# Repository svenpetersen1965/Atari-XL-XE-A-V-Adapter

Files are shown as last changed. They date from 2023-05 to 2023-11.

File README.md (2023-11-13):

# Atari-XL-XE-A-V-Adapter
This is an A/V-Adapter for the Atari 8bit XL and XE. It provides a connector for S-Video, which will work with the XE models and with XL models, that have the S-Video mod.

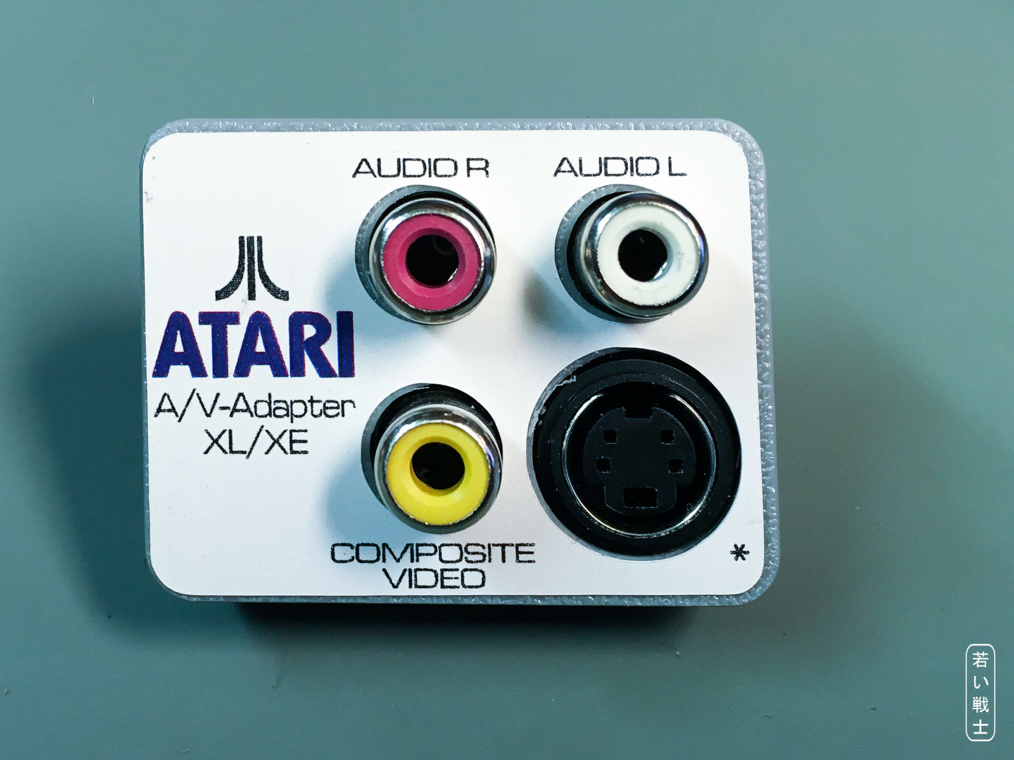
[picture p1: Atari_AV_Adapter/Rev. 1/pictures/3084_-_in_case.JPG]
Atari XL/XE A/V Adapter


The BOM value (13.11.2023) for the PCB and components is 10.87€. This does not include the 3D printed case or any shipping fees to be paid for the components.

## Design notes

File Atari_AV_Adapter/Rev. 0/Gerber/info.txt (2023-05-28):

      
       Board: Atari_AV-Adapter
       Rev.:  0
  
       Files:
       ======
  
       All Gerber files are generated in extended gerber format (RS274X)
       *.TOP        : Film top copper
       *.BOT        :  -"- bottom copper
       *.STC        :  -"- top soldermask 
       *.STS        :  -"- bottom soldermask
       *.PLC        :  -"- silk screen top
       *.PLS        :  -"- silk screen bottom
       *.DK         : Drills plated Through (Excellon)
       *.NDK        : Drills not plated Through (Excellon)
       *.OUT        : Board outline

       Board Size:
       ===========
       Length     :   39.0 mm
       Width      :   29.0 mm
       Thickness  :   1.6 mm
       Material   :   FR 4
       Copper     :   35 um
       Surface    :   HASL
       
       Remarks:
       ========
       Width >= 8mil
       Distance >= 6mil
       Drill >= 0.6mm

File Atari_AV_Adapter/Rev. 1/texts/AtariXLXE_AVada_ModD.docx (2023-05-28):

Atari XL/XE A/V-Adapter Rev. 1

Module Description

# Introduction

The Atari XL/XE-Adapter serves as a breakout module for the 5-pin A/V jack, which allows using off the shelve cables of desired length and quality for connecting the Atari XL/XE to video/audio equipment.

The adapter is passive, it does not improve the video quality, but it helps to prevent video degradation. The S-Video jack works with Atari XL (that are modified only) and XE. The adapter does not generate S-Video!

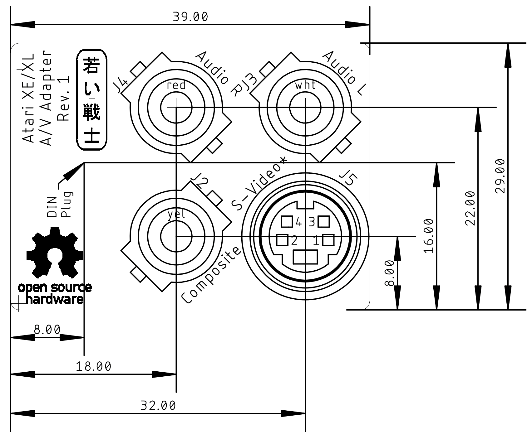
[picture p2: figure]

Figure 1: Dimensions of the PCB

The two audio jacks (Audio L and Audio R) are connected to the same signal, the (mono) Audio Out of the Atari.

A 3D printable case can be found in the project folder as well as a label for this case. The case for Rev. 0 is different from the case for Rev. 1.

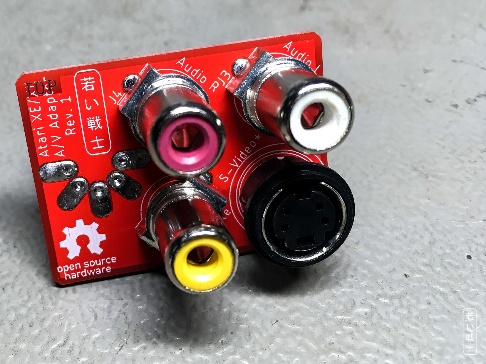
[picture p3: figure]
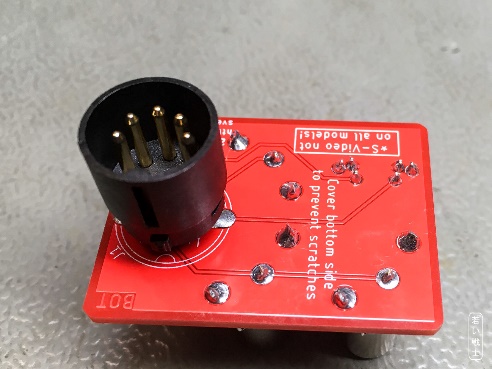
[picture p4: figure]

Figure 2: Top and bottom side of the assembled Atari A/V-Adapter

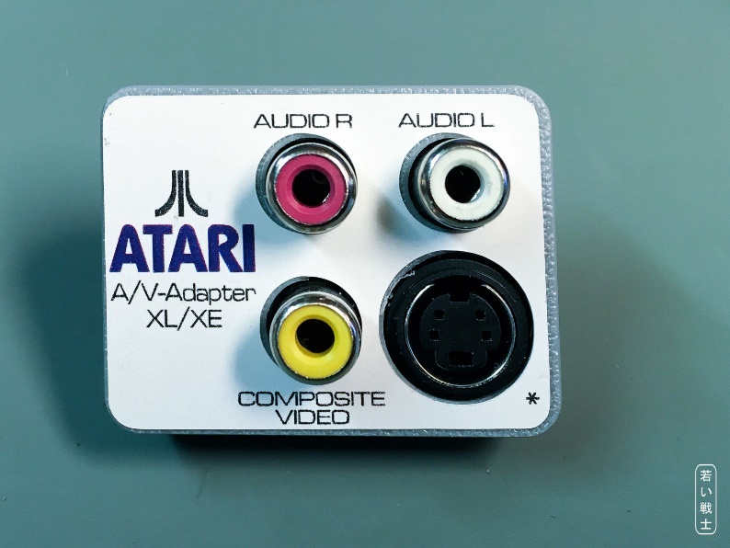
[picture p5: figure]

Figure 3: Atari A/V-Adapter installed in the 3D-printed case

# Connectors

## A/V-Plug – J1

The A/V-Plug for the Atari XE (XL) is the inner part of a Lumberg SV 50 DIN-Plug (180°).

Pin | Signal
1 | Luminance*
2 | GND
3 | Audio Out (mono)
4 | Composite Video
5 | CHROMA*

*XL (with S-Video mod only) and XE

## RCA-Jacks – J2, J3, J4

Connector | Signal
J2 | Composite Video
J3 | Audio Out L (mono!)
J4 | Audio Out R (mono!)

## Mini-DIN (S-Video) jack – J5

A vertical PCB mount Mini-DIN jack (4 circuits)

Pin | Signal
1 | GND (Luminance)
2 | GND (Chrominance)
3 | Luminance
4 | Chrominance

# The DIN-Plug

The DIN-Plug is an essential part of this development. It is the inner part of a Lumberg SV 50 connector, which is not cheap, but it is definitely worth the money, since the flange is taking the forces introduced by the weight of the adapter and the cables. This way, the set-up is not hanging from the contacts, which might even damage those. Do not use a cheap connector without a flange, here.

# Assembly

First, the DIN connector has to be soldered. The pins should be aligned flush to the top side of the PCB. This can be accomplished by putting the PCB top down on a heat resistant, flat surface. Then solder one pin from the top (the solder pads are shaped in a way, that allows doing so), check, if it is really flush and the connector is perpendicular to the board, then solder the remaining pins.

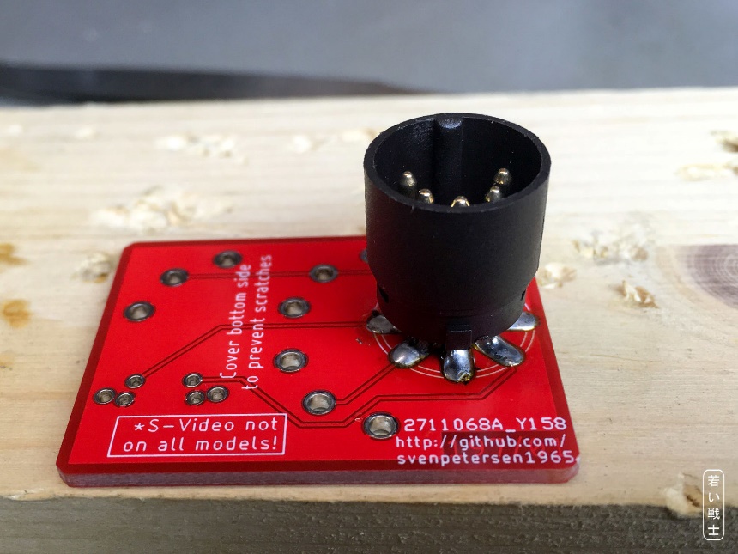
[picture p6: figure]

Figure 4: Aligning the DIN-Connector

Now, place and solder the mini-DIN and finally the RCA jacks. They should be well aligned, too. The ground pins might require more energy to be soldered, so the use of a thick solder tip is recommended and may be even a higher temperature (450°C). After soldering, the pins should be trimmed (shorter than 1.5mm), so they fit into the 3D-Printed case. If you do not use a case, cover the pins with something like duct tape or small drops of hot glue to prevent scratching the case of your Atari.

# Compatibility

The A/V Adapter is compatible with the Atari 8-bit computers XL (composite only) and XE and modified XL for S-Video.

# Acknowledgement

I thank my cooperation partner for this project, Michal Polák. He initiated the project, provided me with the information and tested the A/V Adapter with other computers than the 800XL.

# Revision History

## Rev. 0

- Fully functional prototype

## Rev. 0 → Rev. 1

- The device is turned right, the notch of the DIN and mini-DIN connectors points up (again)
- New case (Rev. 1) required

AtariXLXE_AVada_ModD.docx 28.05.2023 08:06 Drafted by Sven Petersen Page 2 of 2 Doc.-No.: 197-6-01-02

AtariXLXE_AVada_ModD.docx 28.05.2023 08:06 Drafted by Sven Petersen Page 1 of 1 Doc.-No.: 000-6-00-00

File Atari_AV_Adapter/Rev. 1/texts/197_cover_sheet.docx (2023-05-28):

Project Documentation

Atari XL/XE A/V-Adapter

Project number: 197

Revision: 1

Date: 15.11.2022


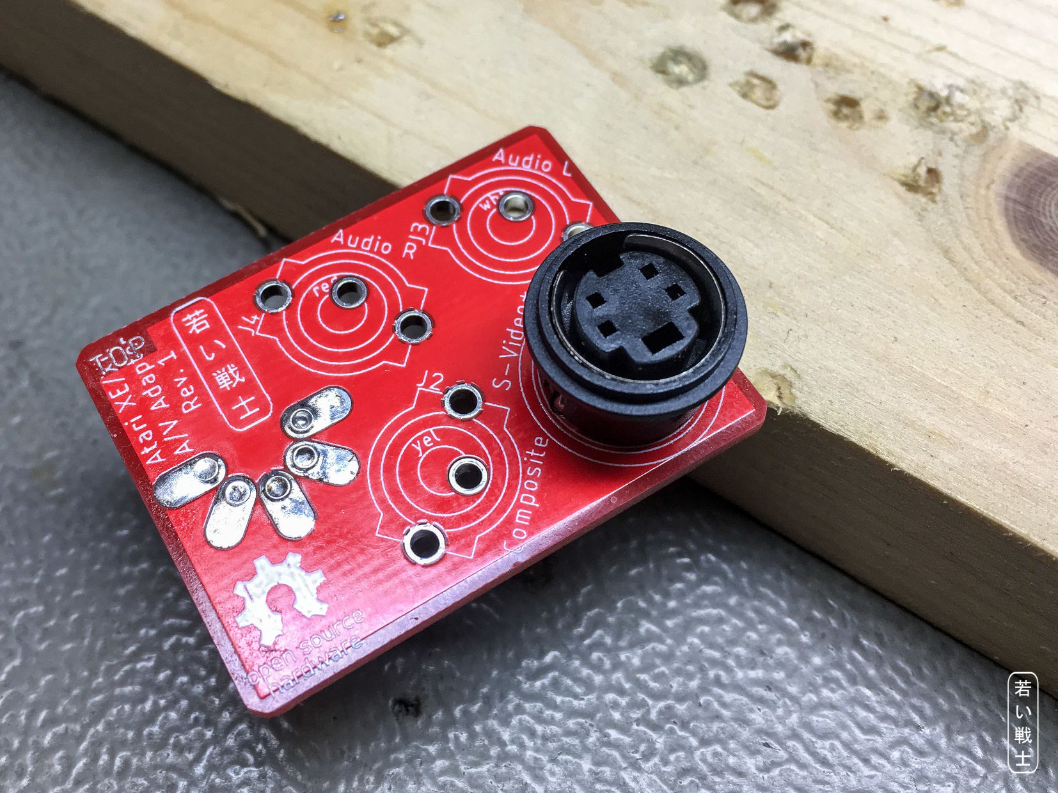
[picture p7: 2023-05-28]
Atari_AV_Adapter/Rev. 1/pictures/2986_-_MiniDIN.JPG

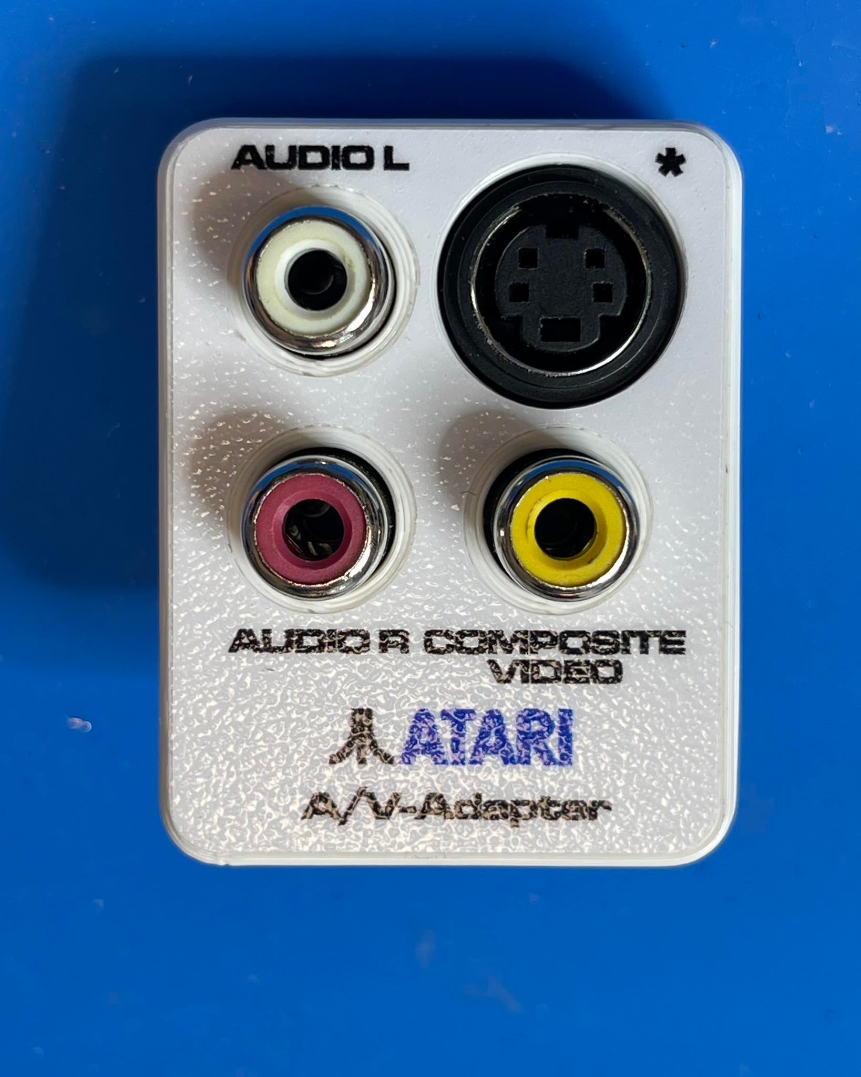
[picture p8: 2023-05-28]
Atari_AV_Adapter/Rev. 0/pictures/310895890_1458096414676044_7788498027069348975_n.jpg

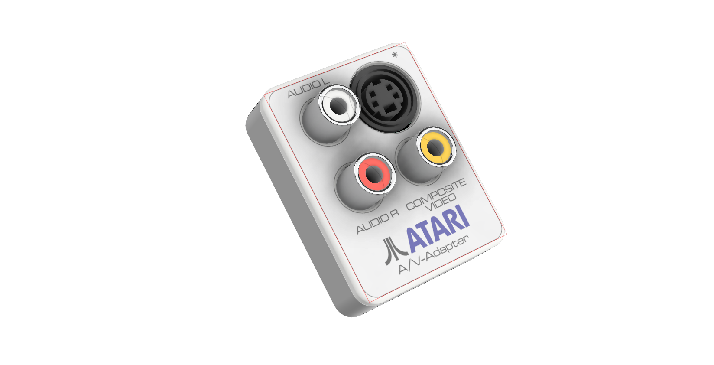
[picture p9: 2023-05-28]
Atari_AV_Adapter/Rev. 0/pictures/Atari A_V Adapter case v0 v2.png

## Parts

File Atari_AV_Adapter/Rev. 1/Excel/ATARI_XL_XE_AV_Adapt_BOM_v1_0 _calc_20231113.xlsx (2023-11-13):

Atari XL/XE A/V-Adaptor Rev. 1
Bill of Material Rev. 1.0 Calculation of 13.11.2023
Pos. | Qty | Value | €/ea | € | Comment
1 | 1 | 197-2-01-01 | 1.00 € | 1.00 € | 2 layer, Cu 35µ, HASL, 39.0mm x 29.0mm, 1.6mm FR4
2 | 1 | RCJ-022 | 1.26 € | 1.26 € | CUI Inc., RCA jack, vertical, red. Mouser: 490-RCJ-022, Digikey: CP-1407-ND. Alternative part: Keystone 577
3 | 1 | RCJ-023 | 1.26 € | 1.26 € | CUI Inc., RCA jack, vertical, white. Mouser: 490-RCJ-023, Digikey: CP-1408-ND. Alternative part: Keystone 584
4 | 1 | RCJ-024 | 1.26 € | 1.26 € | CUI Inc., RCA jack, vertical, yellow. Mouser: 490-RCJ-024, Digikey: CP-1409-ND. Alternative part: Keystone 586
5 | 1 | SV50 | 5.25 € | 5.25 € | Inner part of Lumberg SV 50 (SV 50-8), e.G. Reichelt: LUM SV 50, Newark: 82AH3339 , Farnell: 3549652, TME.eu: SV50, alliedelec.com: 70151556
6 | 1 | solder bridge | 0 | 0.00 € | structure on PCB, close for proper operation
7 | 1 | RTC9028 | 0.84 € | 0.84 € | Mini-DIN, 4p, vertical. Not required for 5-pin and VIC-20. E.g. AliExpress:
 |  |  |  | 0.00 € | RTConnector: RTC9028 (https://www.aliexpress.com/item/4001075948319.html?channel=twinner)
 |  |  |  | 0.00 € | ebay.de (https://www.ebay.de/itm/5Stuck-Leiterplatten-Mount-4-Pin-Buchse-S-Jack-DVD-Mini-DIN-Sockel-Steckverbind/132869605733)
1 |  |  | Total | 10.87 €

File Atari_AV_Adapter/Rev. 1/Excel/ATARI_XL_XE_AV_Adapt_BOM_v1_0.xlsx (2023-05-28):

Atari XL/XE A/V-Adaptor Rev. 1
Bill of Material Rev. 1.0
Pos. | Qty | Value | Footprint | Ref.-No. | Comment
1 | 1 | 197-2-01-01 | 2 Layer | PCB Rev. 1 | 2 layer, Cu 35µ, HASL, 39.0mm x 29.0mm, 1.6mm FR4
2 | 1 | RCJ-022 | RCJ-02X | J4 | CUI Inc., RCA jack, vertical, red. Mouser: 490-RCJ-022, Digikey: CP-1407-ND. Alternative part: Keystone 577
3 | 1 | RCJ-023 | RCJ-02X | J3 | CUI Inc., RCA jack, vertical, white. Mouser: 490-RCJ-023, Digikey: CP-1408-ND. Alternative part: Keystone 584
4 | 1 | RCJ-024 | RCJ-02X | J2 | CUI Inc., RCA jack, vertical, yellow. Mouser: 490-RCJ-024, Digikey: CP-1409-ND. Alternative part: Keystone 586
5 | 1 | SV50 | SV50_INNER | J1 | Inner part of Lumberg SV 50 (SV 50-8), e.G. Reichelt: LUM SV 50, Newark: 82AH3339 , Farnell: 3549652, TME.eu: SV50, alliedelec.com: 70151556
6 | 1 | solder bridge |  | JP1 | structure on PCB, close for proper operation
7 | 1 | RTC9028 | MINIDIN4_V | J5 | Mini-DIN, 4p, vertical. Not required for 5-pin and VIC-20. E.g. AliExpress:
 |  |  |  |  | RTConnector: RTC9028 (https://www.aliexpress.com/item/4001075948319.html?channel=twinner)
 |  |  |  |  | ebay.de (https://www.ebay.de/itm/5Stuck-Leiterplatten-Mount-4-Pin-Buchse-S-Jack-DVD-Mini-DIN-Sockel-Steckverbind/132869605733)

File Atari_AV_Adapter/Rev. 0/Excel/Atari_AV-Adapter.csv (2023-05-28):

Qty | Value | Device | Package | Parts | Description
1 | OPEN_SOURCE_HW | OPEN_SOURCE_HW | OPENHW | U$25
1 | RCJ-022 | RCJ-02X | RCJ-02X | J4
1 | RCJ-023 | RCJ-02X | RCJ-02X | J3
1 | RCJ-024 | RCJ-02X | RCJ-02X | J2
1 | RTC9028 | RTC9028 | MINIDIN4_V | J5 | Mini-DIN, 4p, vertical
1 | SV50 | SV50 | SV50_INNER | J1

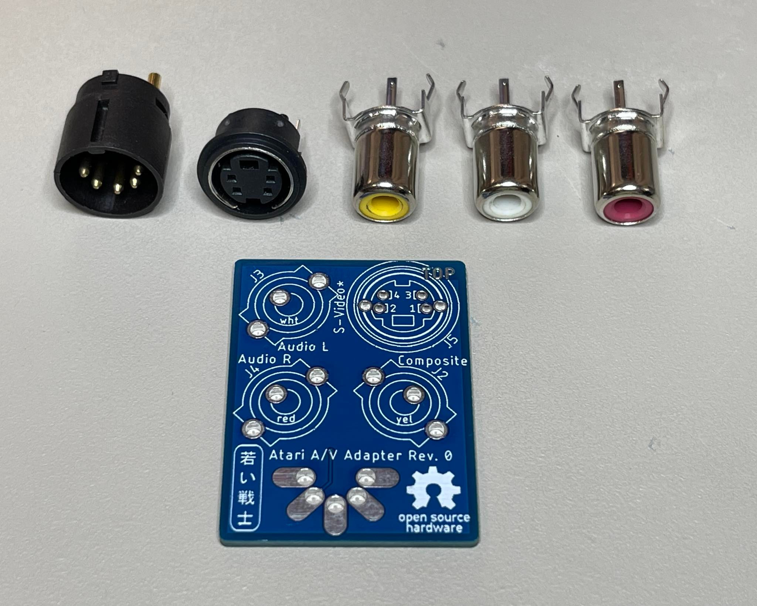
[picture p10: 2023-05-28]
Atari_AV_Adapter/Rev. 0/pictures/PCB_components.jpg

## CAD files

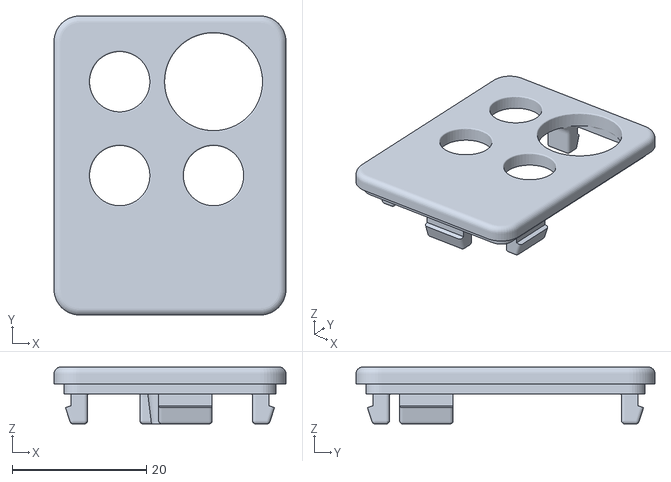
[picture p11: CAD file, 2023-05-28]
Atari_AV_Adapter/3D-printed case/Rev. 0/STL/Atari_AV_top_v0.stl
34.6 x 44.6 x 8.50

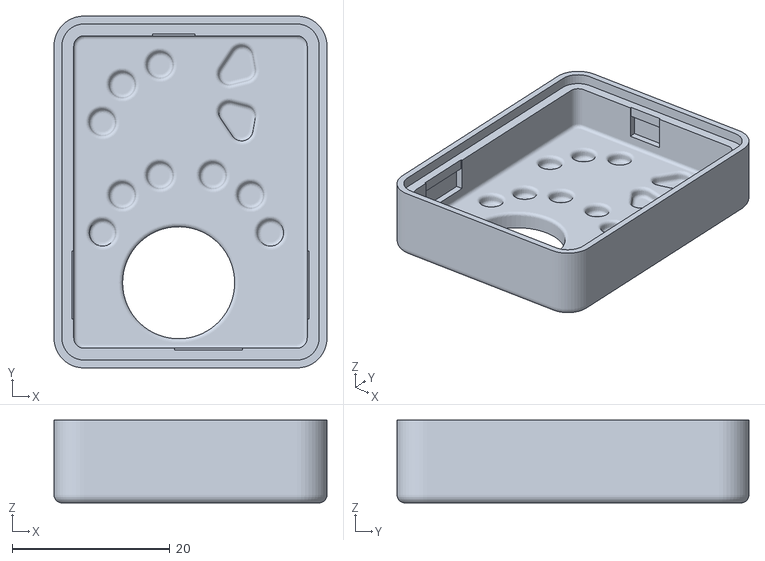
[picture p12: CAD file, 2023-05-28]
Atari_AV_Adapter/3D-printed case/Rev. 1/STL/Atari_AV_bottom_v1.stl
34.6 x 44.6 x 10.5

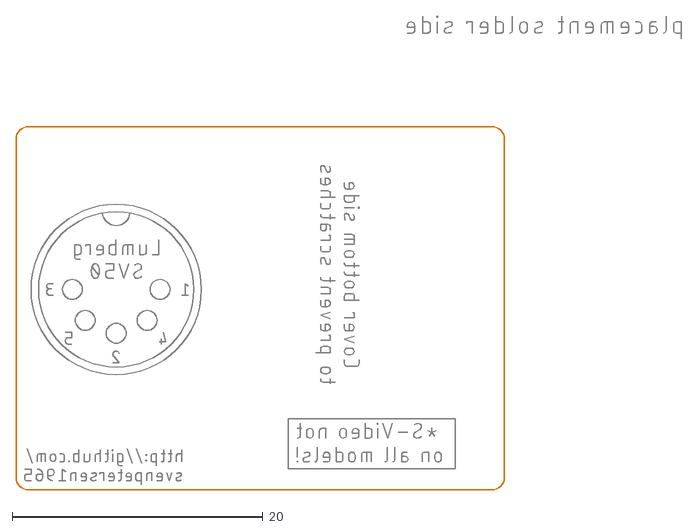
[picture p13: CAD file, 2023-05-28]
Atari_AV_Adapter/Rev. 1/dxf/Atari_AV-Adapter_bottom.dxf
53.1 x 37.8

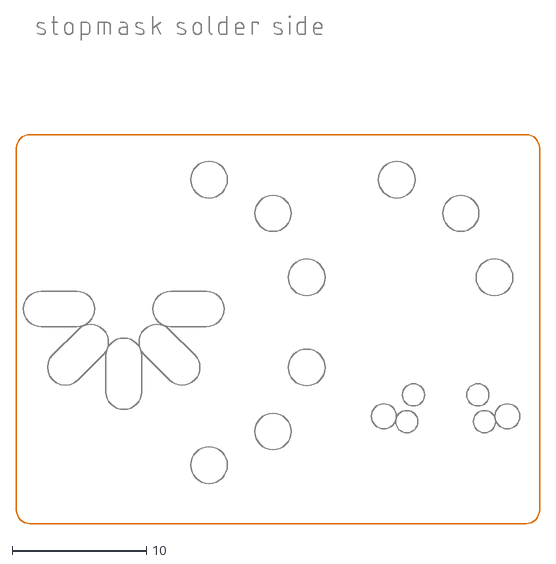
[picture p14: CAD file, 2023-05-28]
Atari_AV_Adapter/Rev. 1/dxf/Atari_AV-Adapter_bottom_pads.dxf
39.0 x 37.8

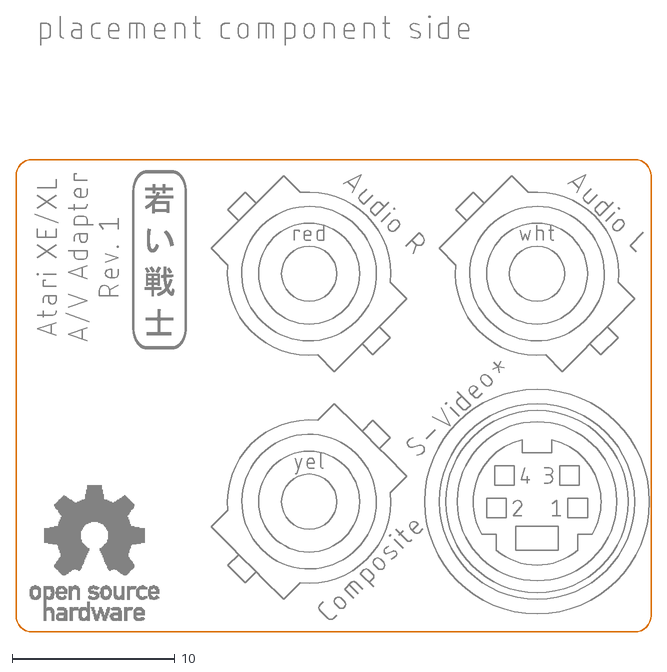
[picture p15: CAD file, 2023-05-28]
Atari_AV_Adapter/Rev. 1/dxf/Atari_AV-Adapter_top.dxf
39.0 x 37.8

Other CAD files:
Atari_AV_Adapter/3D-printed case/Rev. 0/STL/Atari_AV_bottom_v0.stl
Atari_AV_Adapter/3D-printed case/Rev. 0/Fusion 360/Atari AV Adapter case v0 v2.f3d
Atari_AV_Adapter/3D-printed case/Rev. 1/Fusion 360/Atari_XLXE_AV_Rev1.f3d

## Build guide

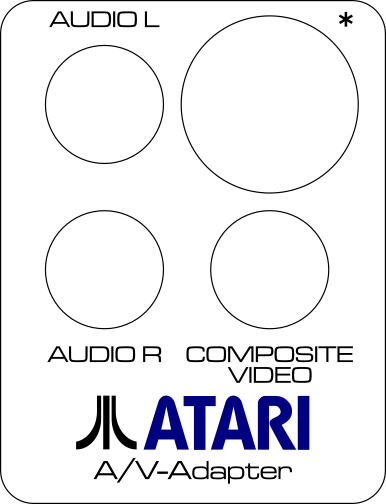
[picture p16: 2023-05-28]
Atari_AV_Adapter/3D-printed case/Rev. 0/Label/atari_AV_label.png

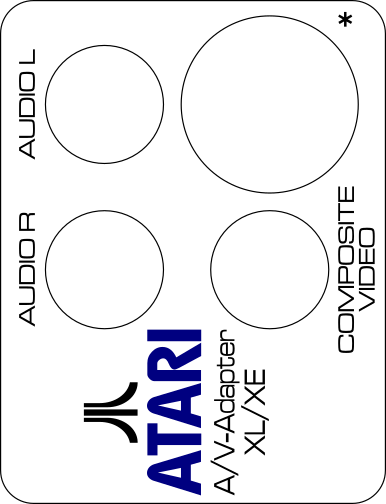
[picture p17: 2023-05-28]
Atari_AV_Adapter/3D-printed case/Rev. 1/Label/Label_v1.png

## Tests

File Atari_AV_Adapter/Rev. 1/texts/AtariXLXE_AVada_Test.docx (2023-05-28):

Atari XL/XE A/V-Adapter Rev. 1

Testing

# Test Setup

The tests were executed with an Atari XL/XE A/V-Adapter Rev. 0 and Rev. 1. These computers were used for testing:

- Atari 800XL
- Atari 800XE
- Atari 130XE (Rev. 0 only)

The retroTINK 2x (used with the HDMI capture device), the Framemeister (used with the TV) and a Samsung smart TV served as video equipment. A 1.5m RCA A/V cable connected the computer to the video equipment.

# Functional Test

The A/V adapter was connected to the computers. The 800XL displayed the composite video signal properly. The 130XE and the 800XE displayed both, the composite and the S-Video signal properly.

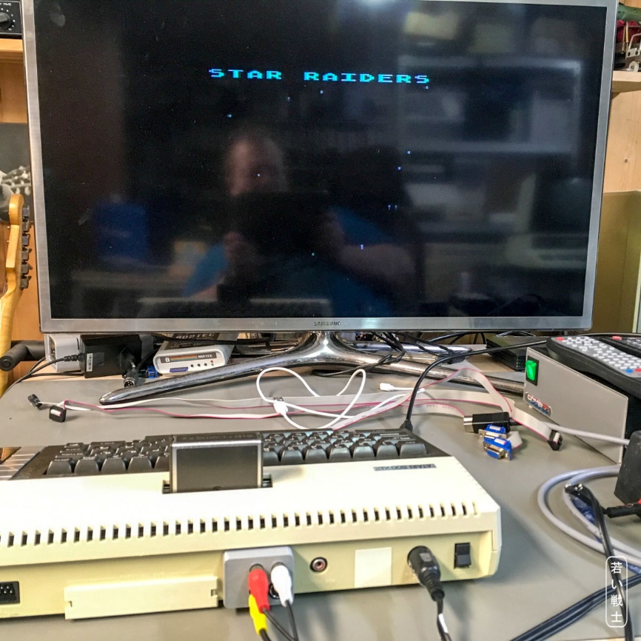
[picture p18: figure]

Figure 1: Testing with the 800XL

# Mechanical Testing

The Atari XL/XE A/V-Adapter Rev. 1did not block any port of the said computers. It fits under the protrusion of the computers’ back side.

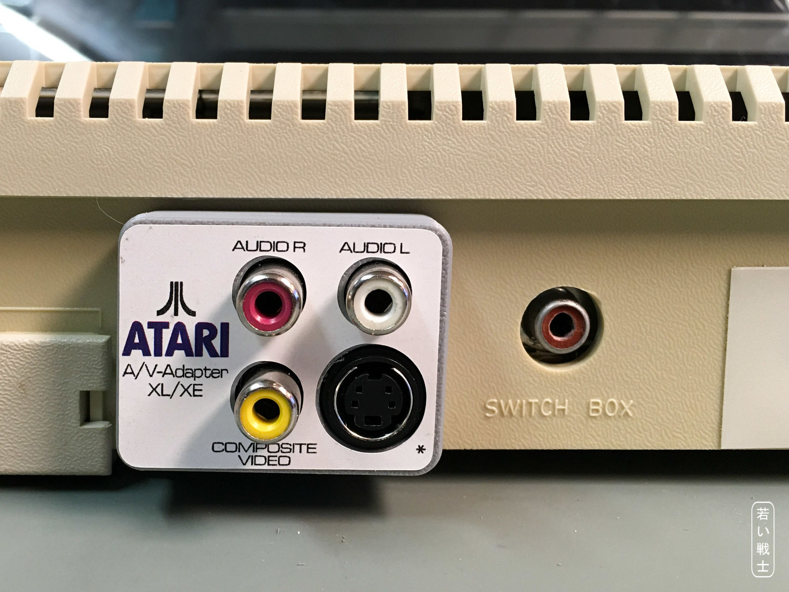
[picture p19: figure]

Figure 2: Test fitting with the 800XL

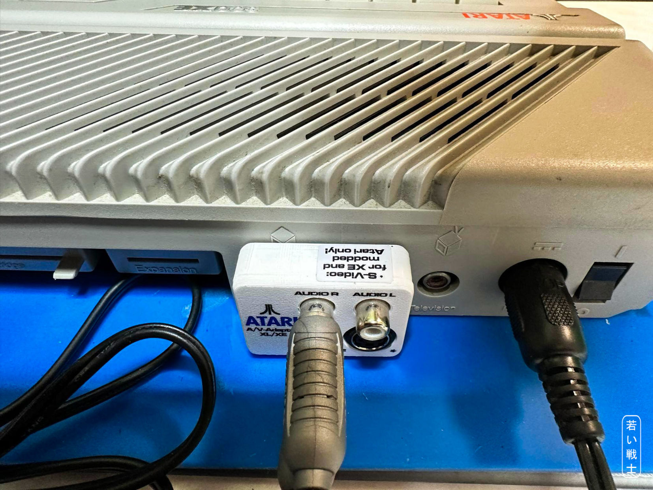
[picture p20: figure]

Figure 3: Test-fitting with the 800XE

# Conclusion

The Atari XL/XE A/V-Adapter Rev. 1 works well with different equipment. The video quality depends very much on the used video equipment. The video adapter will not improve the picture of the computers, since it is passive only, but since it allows to use good, off the shelve cables, it is superior to most hand-made custom cables.

The Atari XL/XE A/V-Adapter Rev. 1 is fully functional.

AtariXLXE_AVada_Test.docx 27.05.2023 19:37 Drafted by Sven Petersen Page 2 of 2 Doc.-No.: 197-6-02-01

AtariXLXE_AVada_Test.docx 27.05.2023 19:37 Drafted by Sven Petersen Page 1 of 1 Doc.-No.: 000-6-00-00

ENZIANWEG 16 ● 83052 BRUCKMÜHL TEL (08062) 728704 ● FAX (08062) 728705

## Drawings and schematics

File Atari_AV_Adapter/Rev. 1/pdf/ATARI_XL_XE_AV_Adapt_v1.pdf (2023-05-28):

# Project Documentation

## Atari XL/XE A/V-Adapter

## Project number: 197

## Revision: 1

## Date: 15.11.2022

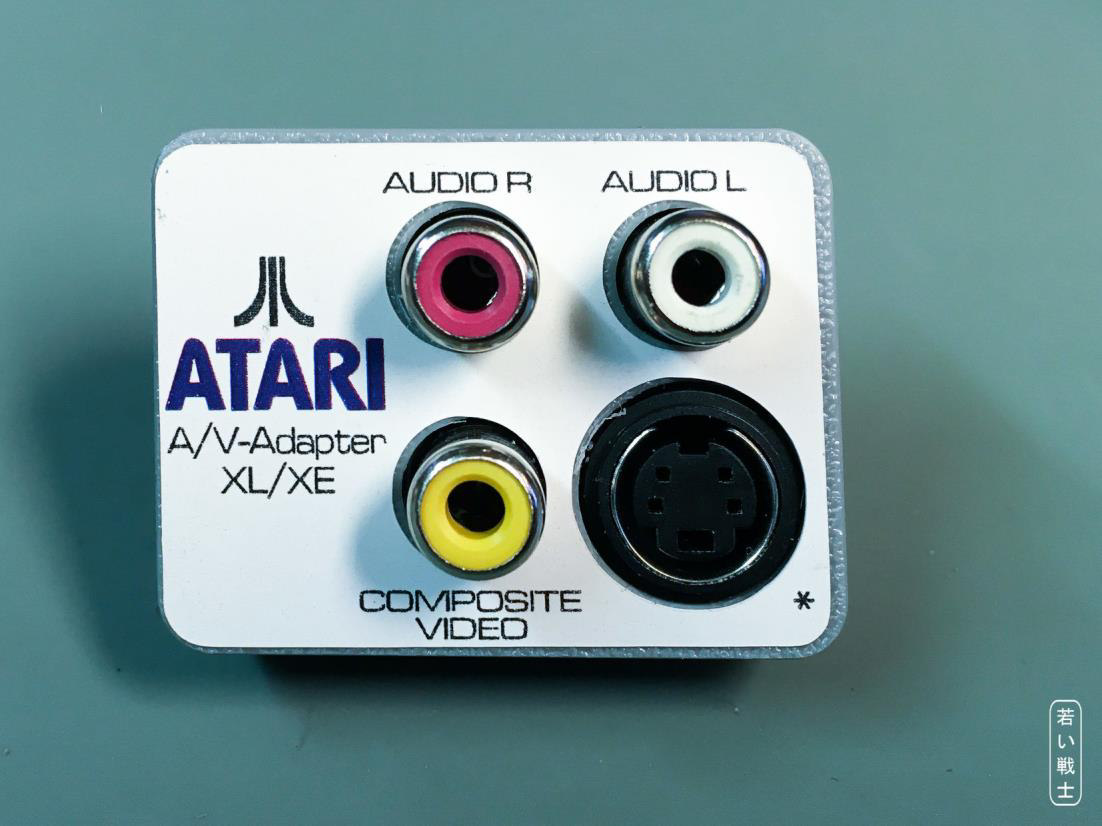
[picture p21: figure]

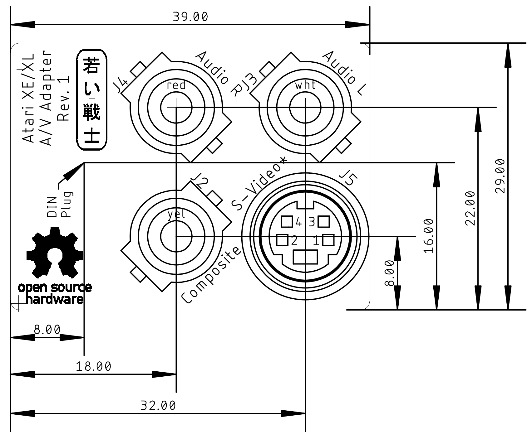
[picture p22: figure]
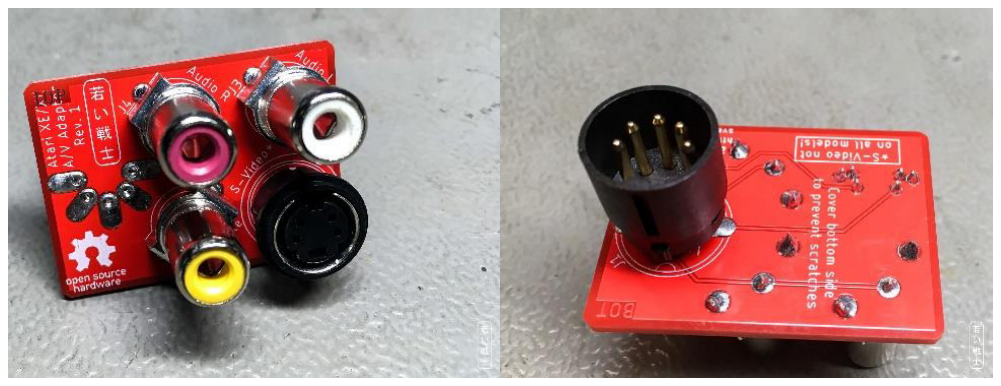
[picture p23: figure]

AtariXLXE_AVada_ModD.docx | | 28.05.2023 08:06
Drafted by Sven Petersen | Page 1 of 3 | Doc.-No.: 197-6-01-02

### Atari XL/XE A/V-Adapter Rev. 1

### Module Description

## Introduction

The Atari XL/XE-Adapter serves as a breakout module for the 5-pin A/V jack, which allows using off the shelve cables of desired length and quality for connecting the Atari XL/XE to video/audio equipment.

The adapter is passive, it does not improve the video quality, but it helps to prevent video degradation. The S-Video jack works with Atari XL (that are modified only) and XE. The adapter does not generate S-Video!

Figure 1: Dimensions of the PCB

The two audio jacks (Audio L and Audio R) are connected to the same signal, the (mono) Audio Out of the Atari.

A 3D printable case can be found in the project folder as well as a label for this case. The case for Rev. 0 is different from the case for Rev. 1.

Figure 2: Top and bottom side of the assembled Atari A/V-Adapter

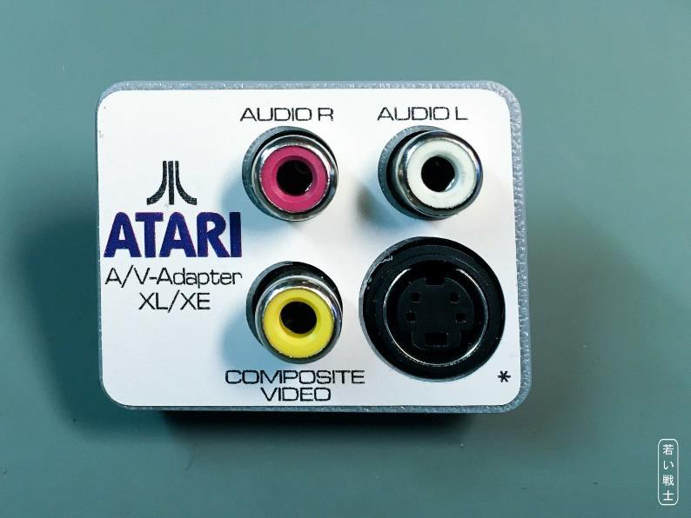
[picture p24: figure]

AtariXLXE_AVada_ModD.docx | | 28.05.2023 08:06
Drafted by Sven Petersen | Page 2 of 3 | Doc.-No.: 197-6-01-02

Figure 3: Atari A/V-Adapter installed in the 3D-printed case

## Connectors

### A/V-Plug – J1

The A/V-Plug for the Atari XE (XL) is the inner part of a Lumberg SV 50 DIN-Plug (180°).

Pin Signal
1 Luminance*
2 GND
3 Audio Out (mono)
4 Composite Video
5 CHROMA*

*XL (with S-Video mod only) and XE

### RCA-Jacks – J2, J3, J4

Connector Signal
J2 | Composite Video
J3 | Audio Out L (mono!)
J4 | Audio Out R (mono!)

### Mini-DIN (S-Video) jack – J5

A vertical PCB mount Mini-DIN jack (4 circuits)

Pin Signal
1 GND (Luminance)
2 GND (Chrominance)
3 Luminance
4 Chrominance

## The DIN-Plug

The DIN-Plug is an essential part of this development. It is the inner part of a Lumberg SV 50 connector, which is not cheap, but it is definitely worth the money, since the flange is taking the forces introduced by the weight of the adapter and the cables. This way, the set-up is not hanging

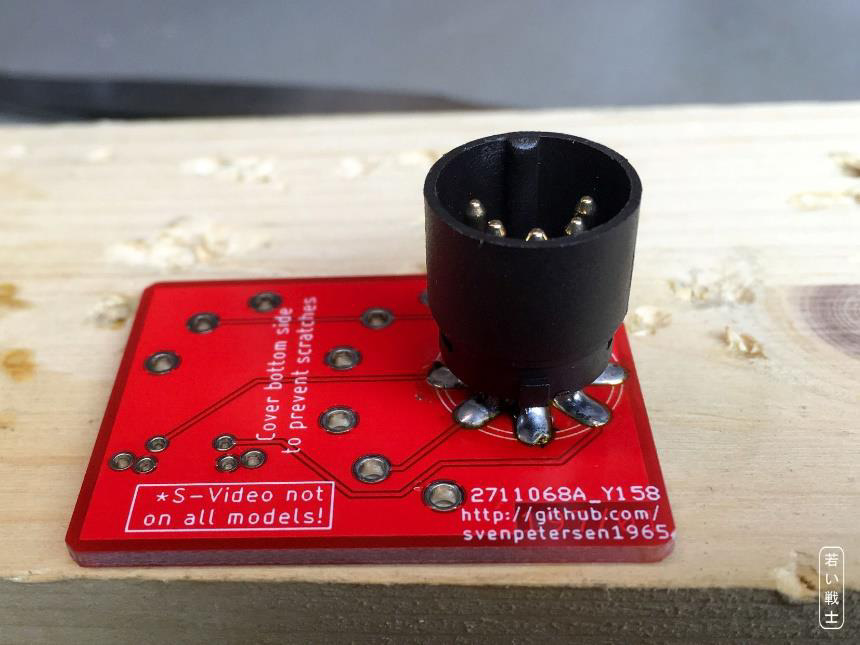
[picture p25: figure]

AtariXLXE_AVada_ModD.docx | | 28.05.2023 08:06
Drafted by Sven Petersen | Page 3 of 3 | Doc.-No.: 197-6-01-02

from the contacts, which might even damage those. Do not use a cheap connector without a flange, here.

## Assembly

First, the DIN connector has to be soldered. The pins should be aligned flush to the top side of the PCB. This can be accomplished by putting the PCB top down on a heat resistant, flat surface. Then solder one pin from the top (the solder pads are shaped in a way, that allows doing so), check, if it is really flush and the connector is perpendicular to the board, then solder the remaining pins.

Figure 4: Aligning the DIN-Connector

Now, place and solder the mini-DIN and finally the RCA jacks. They should be well aligned, too. The ground pins might require more energy to be soldered, so the use of a thick solder tip is recommended and may be even a higher temperature (450°C). After soldering, the pins should be trimmed (shorter than 1.5mm), so they fit into the 3D-Printed case. If you do not use a case, cover the pins with something like duct tape or small drops of hot glue to prevent scratching the case of your Atari.

## Compatibility

The A/V Adapter is compatible with the Atari 8-bit computers XL (composite only) and XE and modified XL for S-Video.

## Acknowledgement

I thank my cooperation partner for this project, Michal Pol·k. He initiated the project, provided me with the information and tested the A/V Adapter with other computers than the 800XL.

## Revision History

### Rev. 0

- Fully functional prototype
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

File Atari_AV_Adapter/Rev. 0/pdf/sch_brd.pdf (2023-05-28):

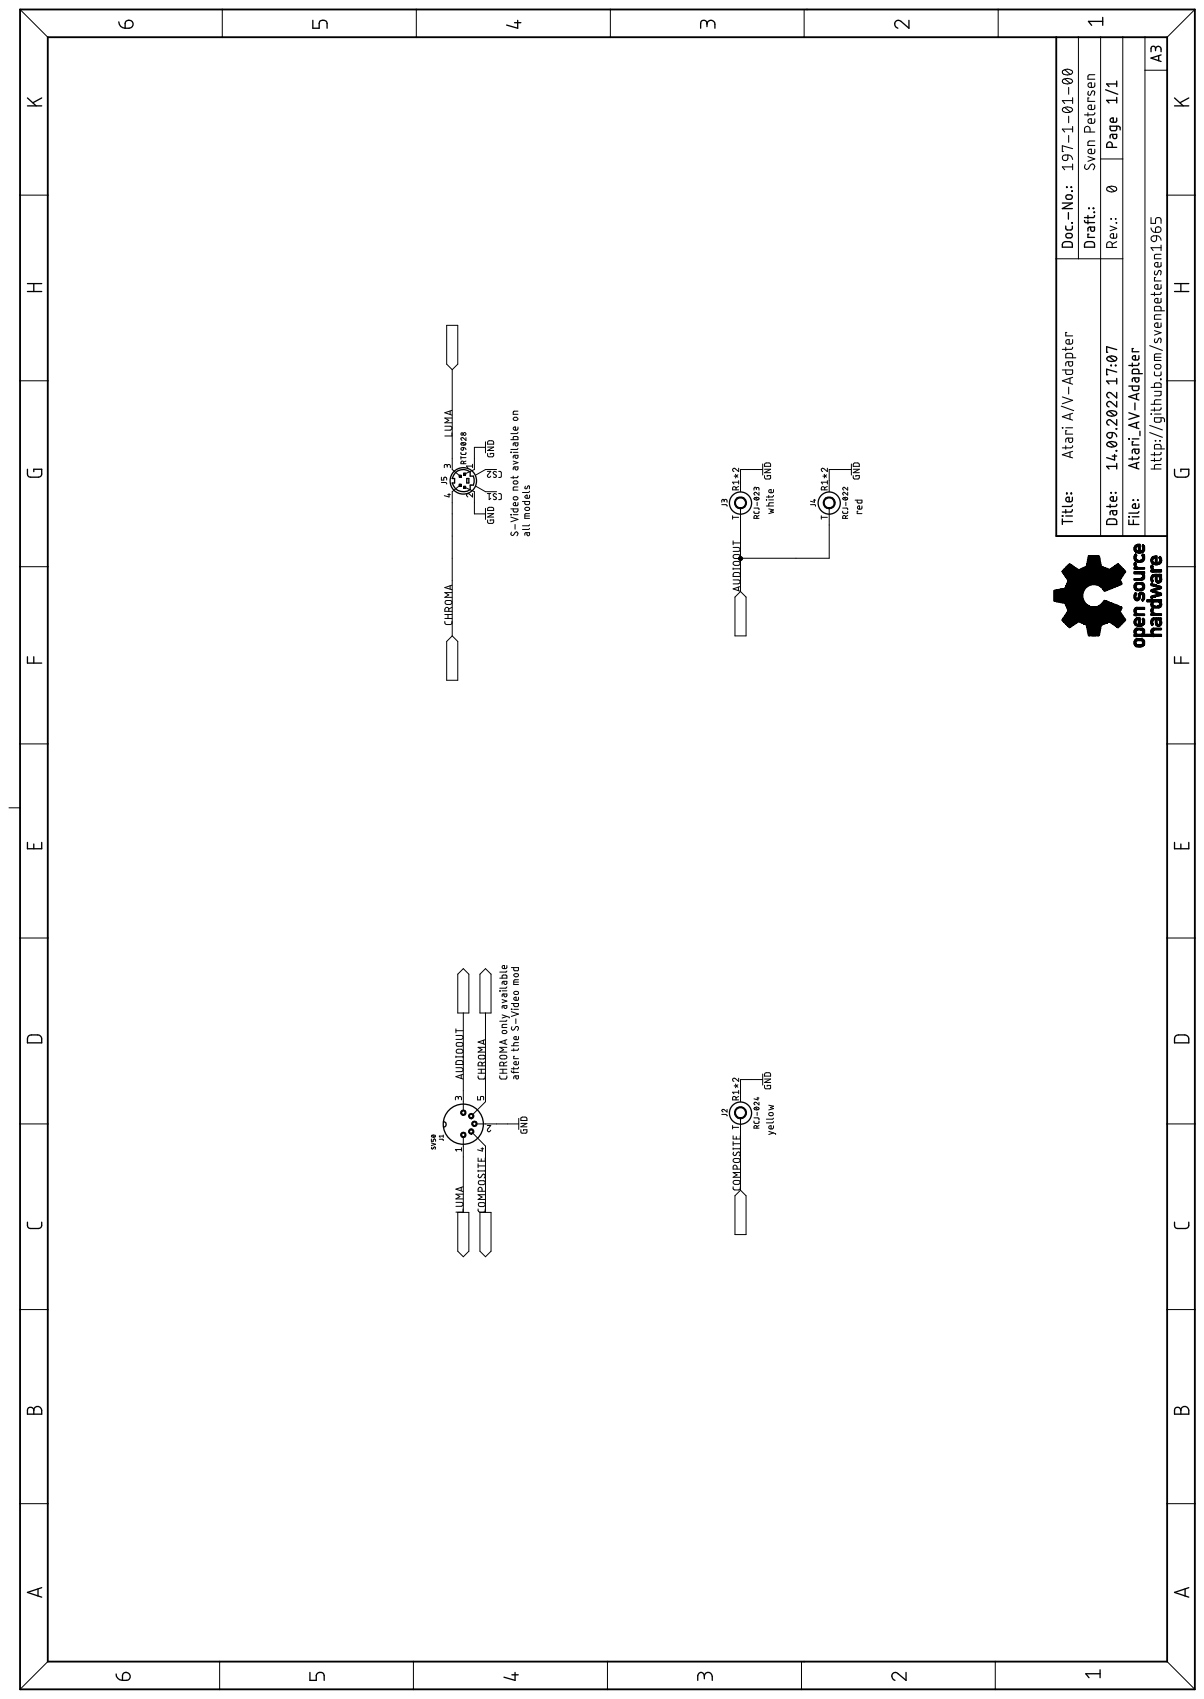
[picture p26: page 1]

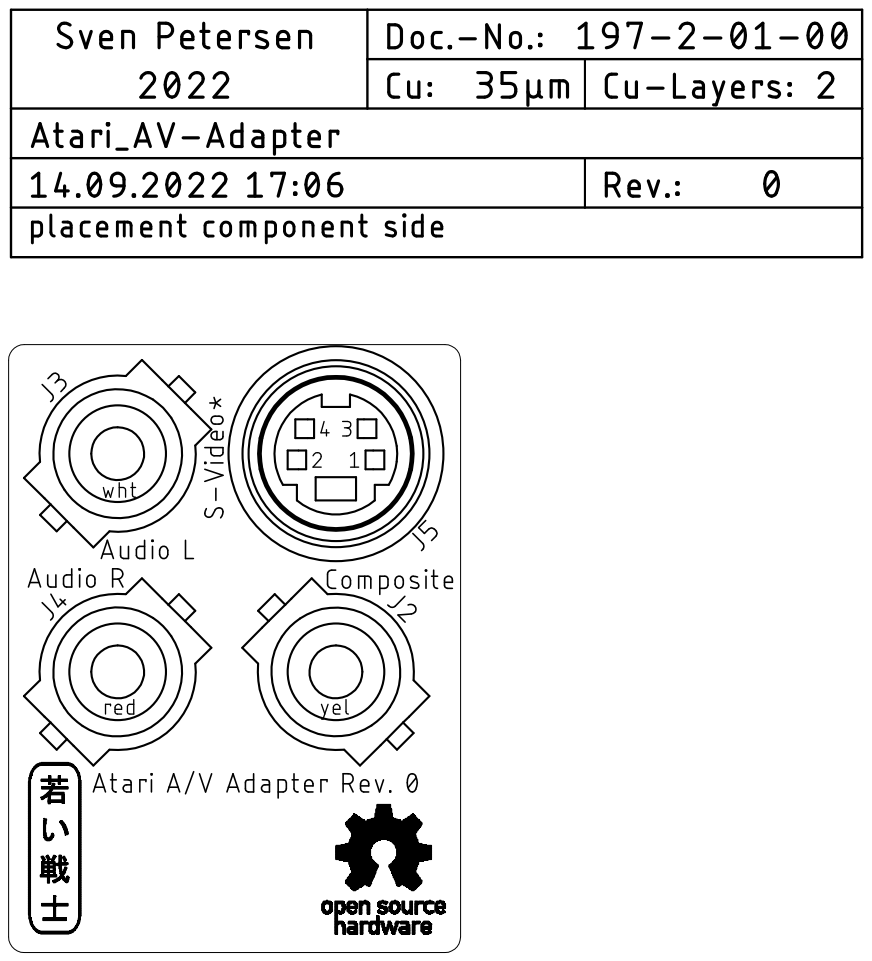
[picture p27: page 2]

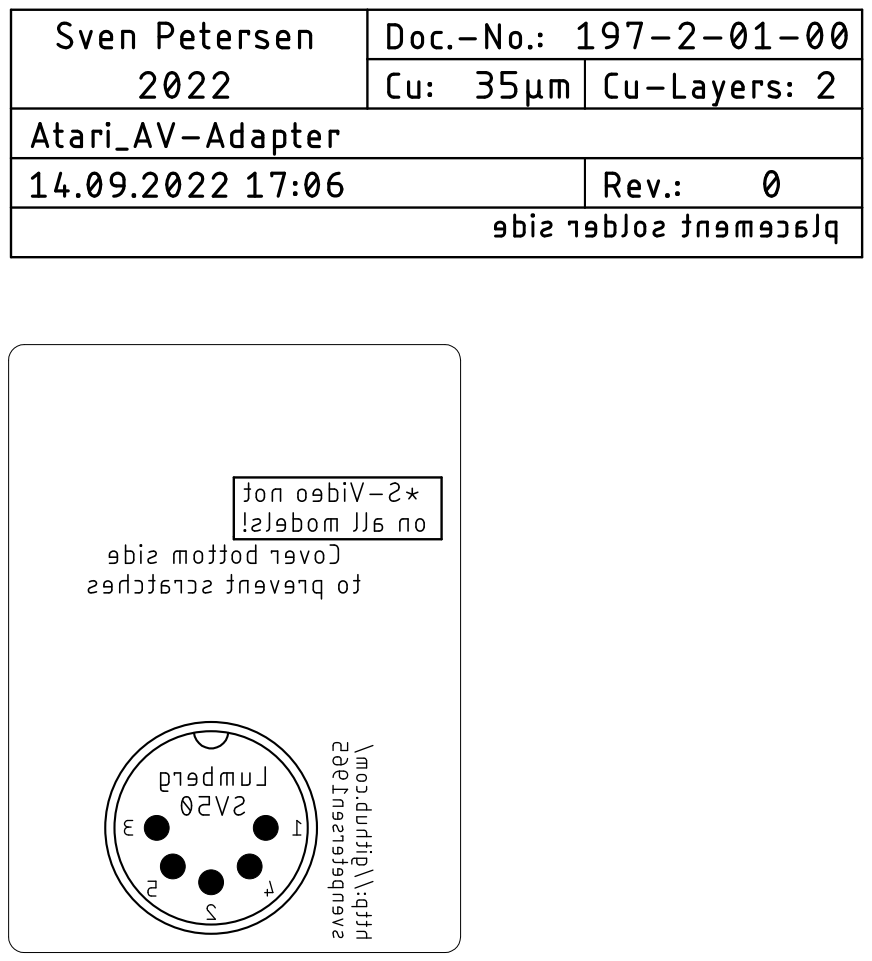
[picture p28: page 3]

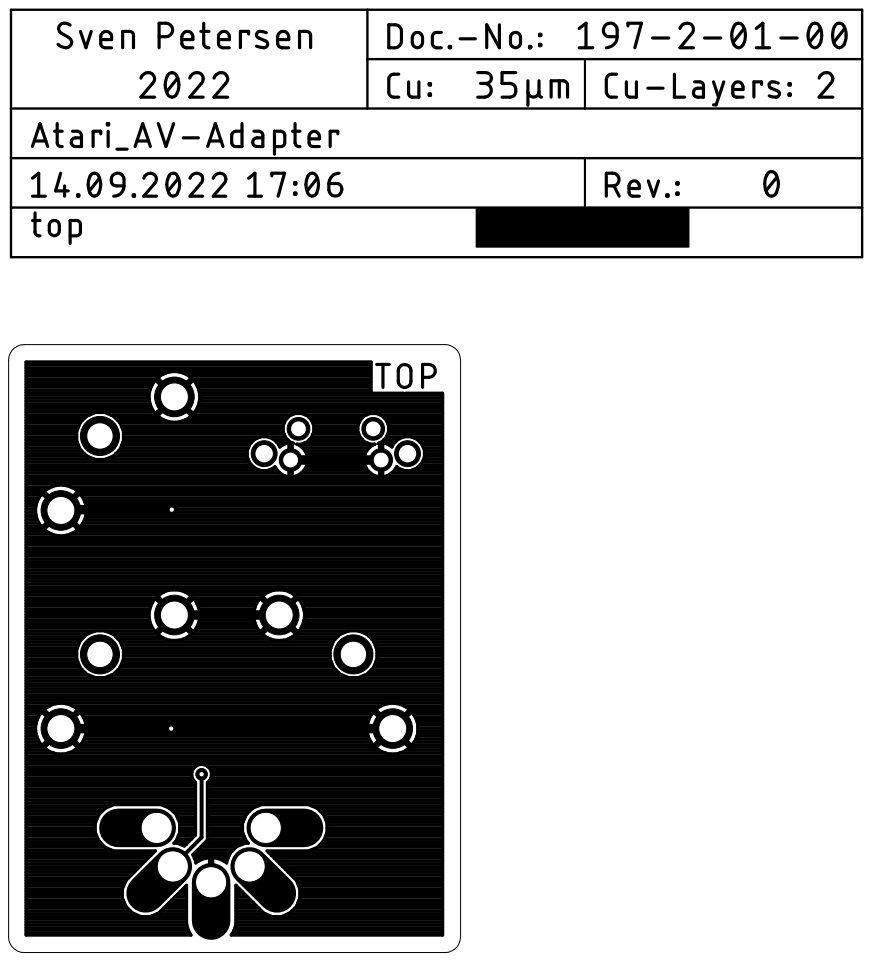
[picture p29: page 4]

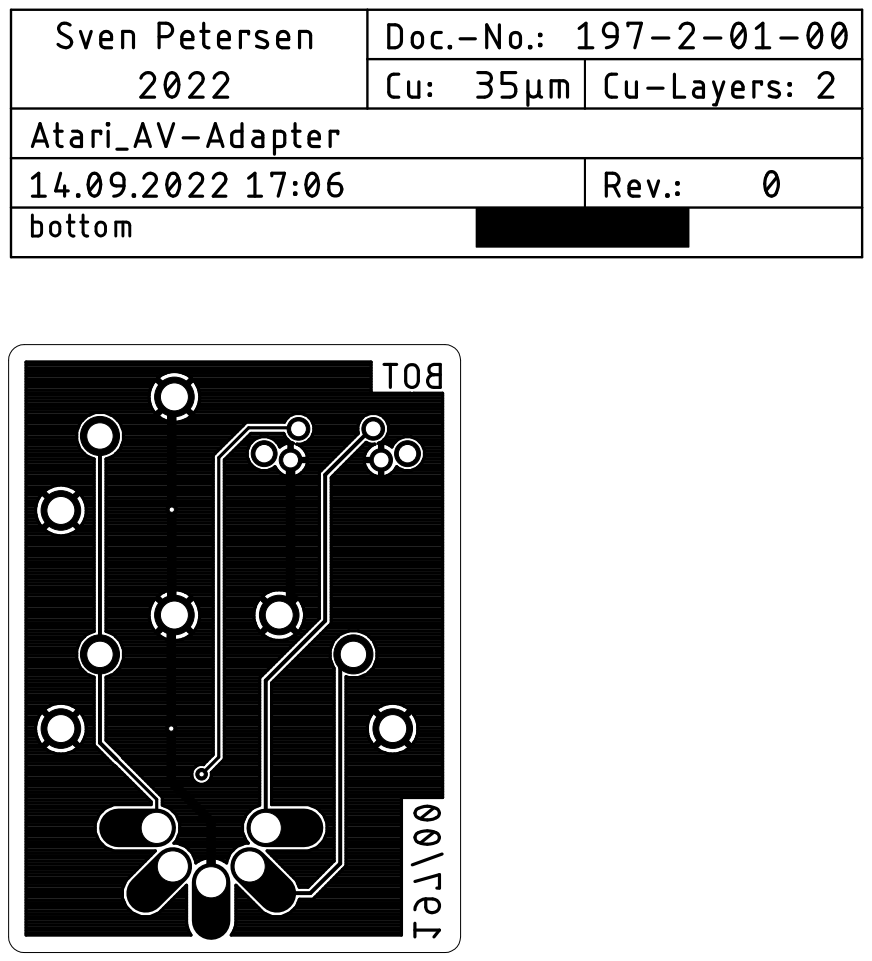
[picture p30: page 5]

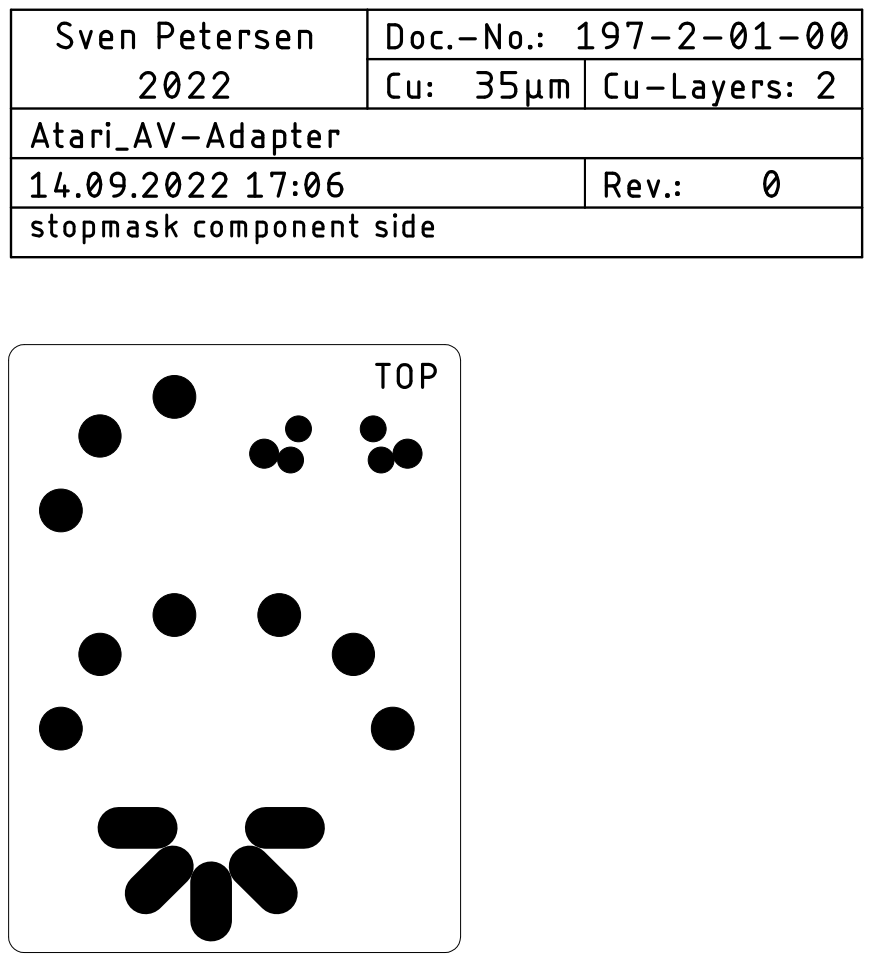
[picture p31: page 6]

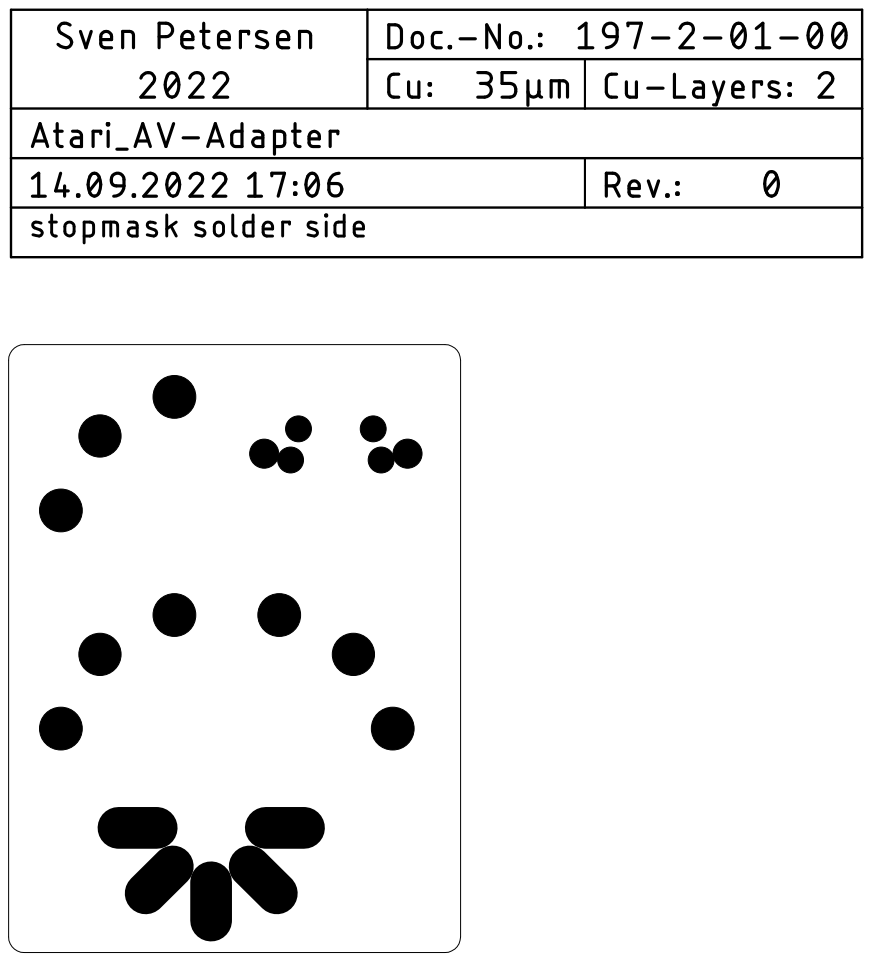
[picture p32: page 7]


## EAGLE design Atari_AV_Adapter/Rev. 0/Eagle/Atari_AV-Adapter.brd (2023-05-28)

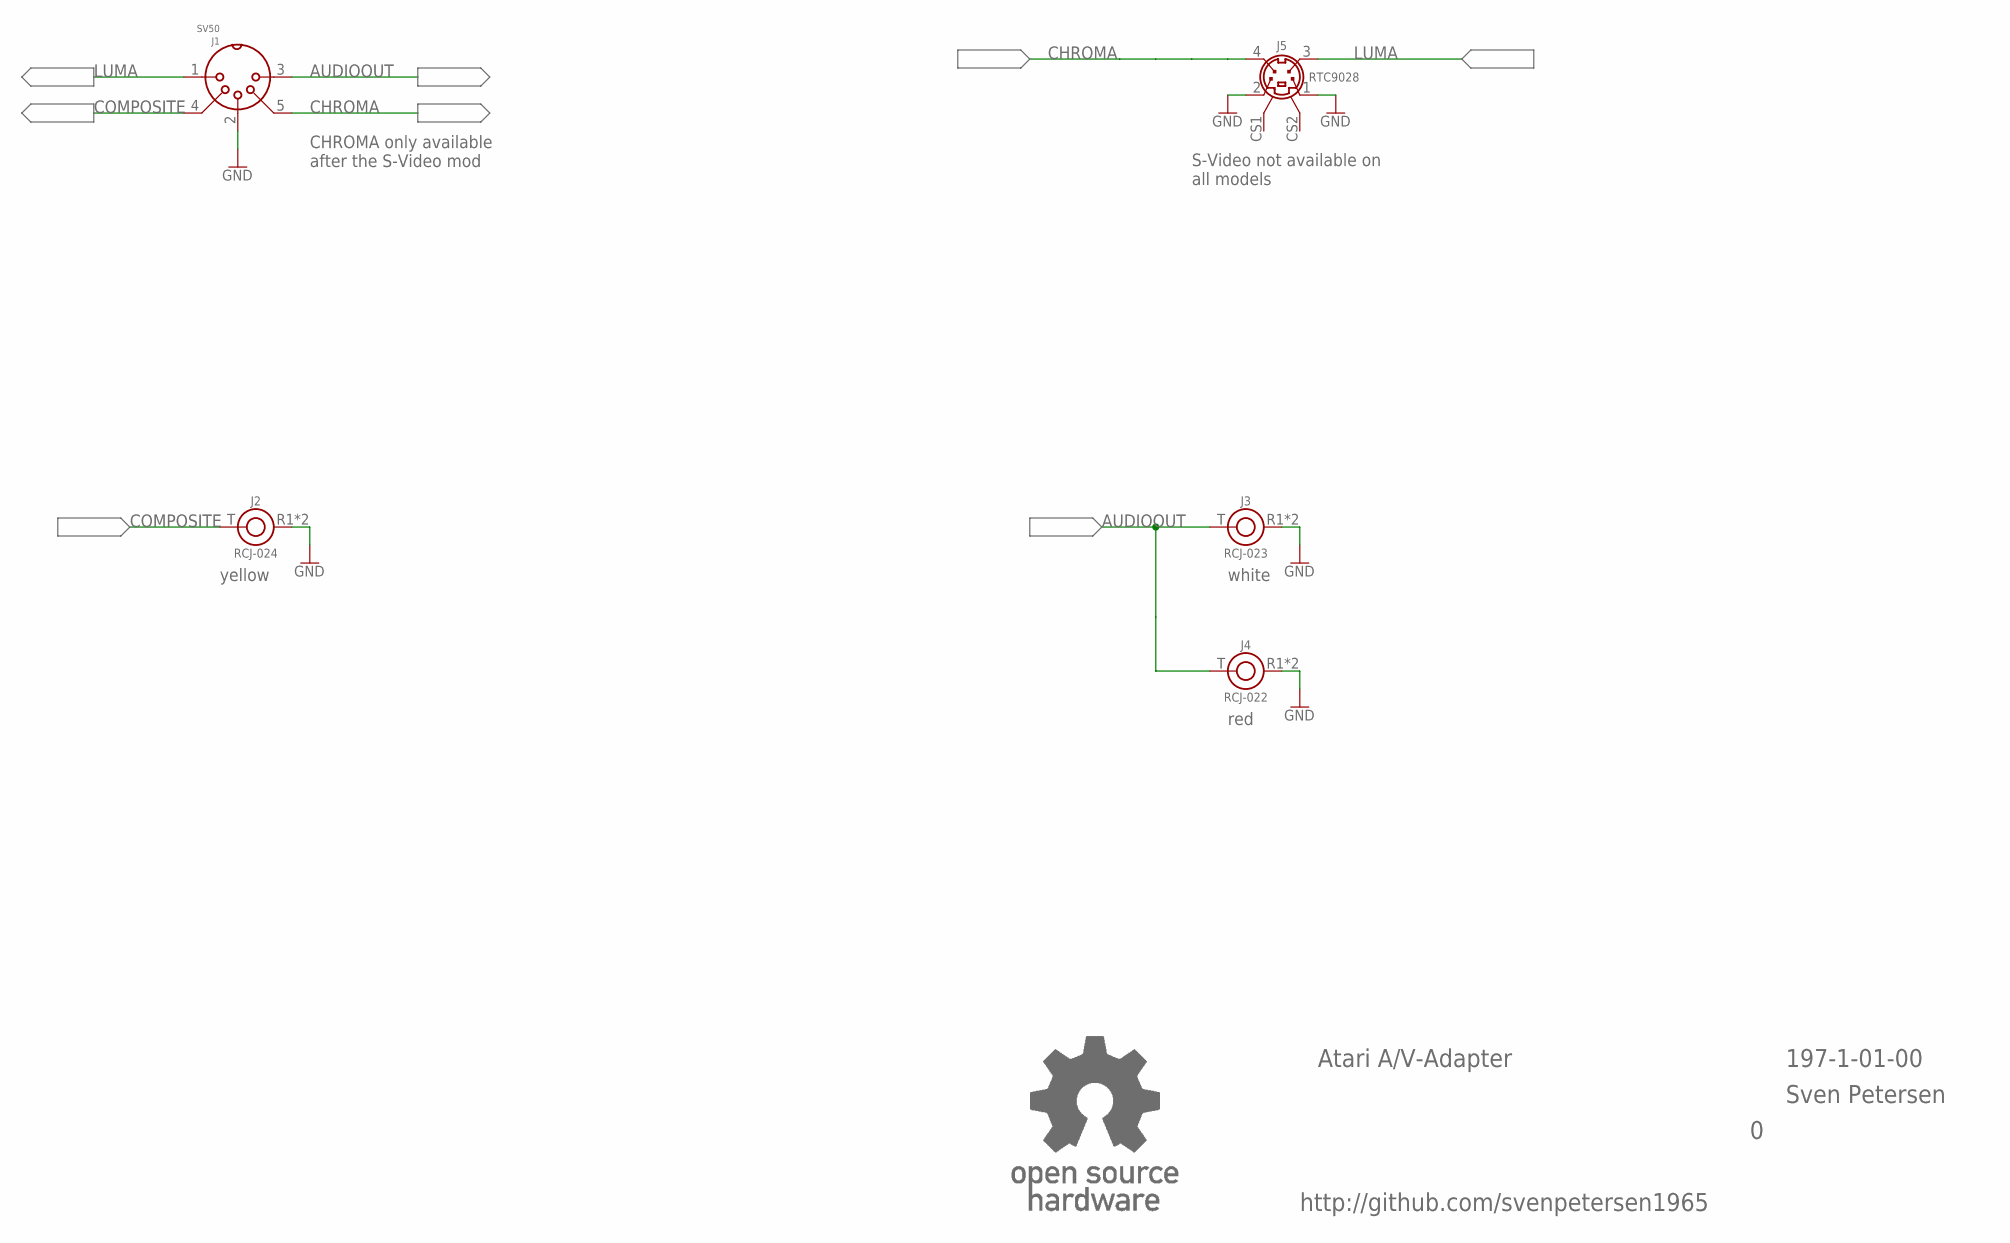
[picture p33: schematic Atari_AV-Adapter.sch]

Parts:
J1: SV50; SV50_INNER
J2: RCJ-024; RCJ-02X
J3: RCJ-023; RCJ-02X
J4: RCJ-022; RCJ-02X
J5: RTC9028; MINIDIN4_V
U$25: OPEN_SOURCE_HW; OPENHW

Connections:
AUDIOOUT: J1.3, J3.T, J4.T
CHROMA: J1.5, J5.4
COMPOSITE: J1.4, J2.T
GND: J1.2, J2.R1 (R), J2.R2 (R), J3.R1 (R), J3.R2 (R), J4.R1 (R), J4.R2 (R), J5.1, J5.2
LUMA: J1.1, J5.3

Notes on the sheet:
Atari A/V-Adapter
197-1-01-00
Sven Petersen
http://github.com/svenpetersen1965
CHROMA only available after the S-Video mod
S-Video not available on all models
white
red
yellow

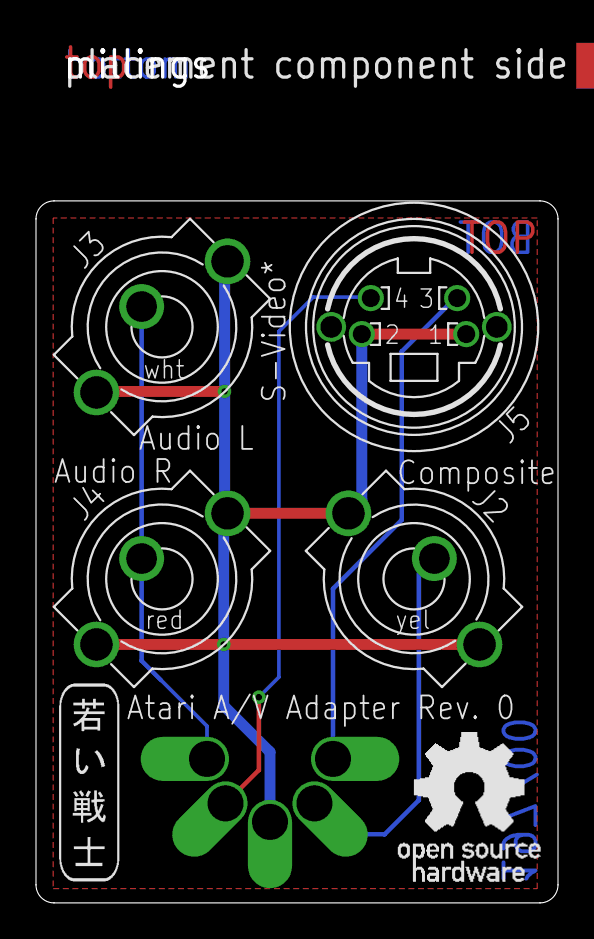
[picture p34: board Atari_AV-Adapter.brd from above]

Board: 2 copper layers, 29.0 x 39.0 mm, 9 parts (1 on the bottom side), 5 nets.

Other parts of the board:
U$22: 2LAYER
U$23: SVEN_TAG
U$24: PCB-TITLE/

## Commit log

2023-05-28 Initial upload
    [ATARI_XL_XE_AV_Adapt_BOM_v1_0.xlsx, Atari AV Adapter case v0 v2.f3d, Atari_AV-Adapter.brd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]
2023-11-13 BOM value calculation
    [ATARI_XL_XE_AV_Adapt_BOM_v1_0 _calc_20231113.xlsx]
